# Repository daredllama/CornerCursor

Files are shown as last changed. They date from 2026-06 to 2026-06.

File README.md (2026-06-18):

**Reviewer, please look at the "LookOut Vids" folder here (https://drive.google.com/drive/folders/1z2TElufV9nIlRgEDV5de165D_nGBTV_t?usp=drive_link) to count the hours from those videos. The videos are named by their date (month.day). It should constitute about 16 hours, considering each second of a video is one MINUTE of actual time (The LookOut lapse program takes one photo every minute). For further inquiries, you can reach out to Evan Gan about the hours/videos.

# CornerCursor

A trackball mouse with 2 configurable buttons and a scroll ring. Made to be positioned on the corner of a laptop so that CADding is easier in any location.

Hardware created through Onshape. PCB made through KiCad. Firmware developed through VSCode.

## Features

- 3d printed case 
- Trackball navigation using PMW-3360 sensor
- Scroll Ring using 40 magnets with Hall Effect sensors
- 2 buttons
- Firmware designed for CAD use in Onshape

## Status

Currently unfinished. CAD, KiCAD, and Firmware are complete, but no actual model has been built. Debugging afterwards would also be expected.

## CAD Model

This is the overall build for the CornerCursor, which includes the case and the trackball.
Made using Onshape



## PCB

This is the schematic, PCB, and a render of the board. Note that the off-board component, such as the Hall effect sensor and USB-C connector, is not shown on the PCB> 

Schematic



PCB



Render

CornerCursor

## Firmware

Firmware sets up a 2-button trackball mouse that uses a PMW3360 sensor and a scroll ring.

To flash the software onto the board, connect your device to the mouse. A RPI-RP2 drive should show up, at which point you can drag the given UF2 file. To flash it again, hold the BOOT button and press the RESET button on the board.

## Assembly

1. Solder the necessary parts on the PCB, using the schematic and PCB image as reference. (Remember, PMW 3360 has its won lens)
2. Attach the board onto the bottom case using 2 M3X2 screws (They will go into plastic).
3. Wire the Hall effect sensor through the hole on the part named "top".
4. Attach the "top" part to the base case using 2 M3x8 screws.
5. Screw the two buttons to the bottom base using 4 M3x6 screws.
6. Attach the top case to the bottom case using 3 M3x12 screws.
7. Place the big bearing on the "top" part and attach neodymium magnets to the ring.
8. Place static bearings into divots in the "top" part and then place the trackball.

## Bill oF Materials

Full Bill of Materials located in the BOM file.

## Notes

AI Usage in this project was used for research, such as tutorials and datasheets; none of the code or CAD is AI-generated

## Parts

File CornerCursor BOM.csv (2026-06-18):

CornerCursor
BILL OF MATERIALS
Item | Quatitiy | Unit Price | Total Price | Notes
PMW3360 Sensor | 1.00 | 10.00 | 10.00
38mm trackball | 1.00 | 9.99 | 9.99 | https://ploopy.co/shop/tracking-ball/
W25Q128JVS Flash Storage | 1.00 | 2.00 | 2.00
ABM8-272-T3 Crystal | 1.00 | 0.60 | 0.60
TCR2F19 LDO regulator | 1.00 | 0.20 | 0.20
TLV73333PDBVR LDO regulator | 1.00 | 0.20 | 0.20
RP2040 chip | 1.00 | 1.00 | 1.00
D2LS-20M switch | 2.00 | 1.50 | 3.00
100n capacitor (Metric 0603) | 11.00 | 0.25 | 2.75
1u capactior (Metric 0603) | 5.00 | 0.25 | 1.25
0.1u capacitor (Metric 0603) | 1.00 | 0.25 | 0.25
15p capacitor (Metric 0603) | 2.00 | 0.25 | 0.50
4.7u capacitor (Metric 0603) | 1.00 | 0.25 | 0.25
39 resisitor (Metric 0603) | 1.00 | 0.20 | 0.20
10k resisitor (Metric 0603) | 2.00 | 0.20 | 0.40
27.4 resistor (Metric 0603) | 2.00 | 0.20 | 0.40
1k resistor (Metric 0603) | 2.00 | 0.20 | 0.40
SS49E Hall Effect sensor | 2.00 | 3.00 | 6.00
USB C to 4 Pin Connector | 5.00 | 1.00 | 5.00
B3S-1000 switch | 2.00 | 0.75 | 1.50
2mm Zirconia Oxide Static Bearing | 3.00 | 2.00 | 6.00
2x2mm neodymium cylinder magnets (axially magnetized) | 40.00 | 0.15 | 6.00
6808-ZZ Ball Bearing 40x52x7 Shielded | 1.00 | 22.00 | 22.00
Wires to hookup hall sensor |  |  | 0.00
M3x6 countersunk screws (Buttons) | 4.00 | 0.20 | 0.80
M3x8 countersunk screws (Top) | 2.00 | 0.20 | 0.40
M3x2 countersunk screws (Board) | 2.00 | 0.20 | 0.40
M3x12 countersunk screws (Case) | 3.00 | 0.20 | 0.60
 |  | Price for All: | 82.09

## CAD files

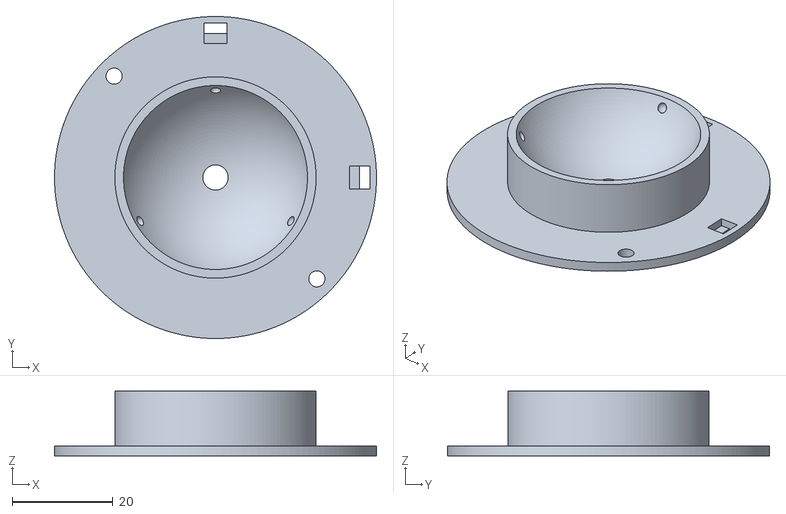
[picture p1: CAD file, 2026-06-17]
CAD/top.stl
64.0 x 64.0 x 12.9

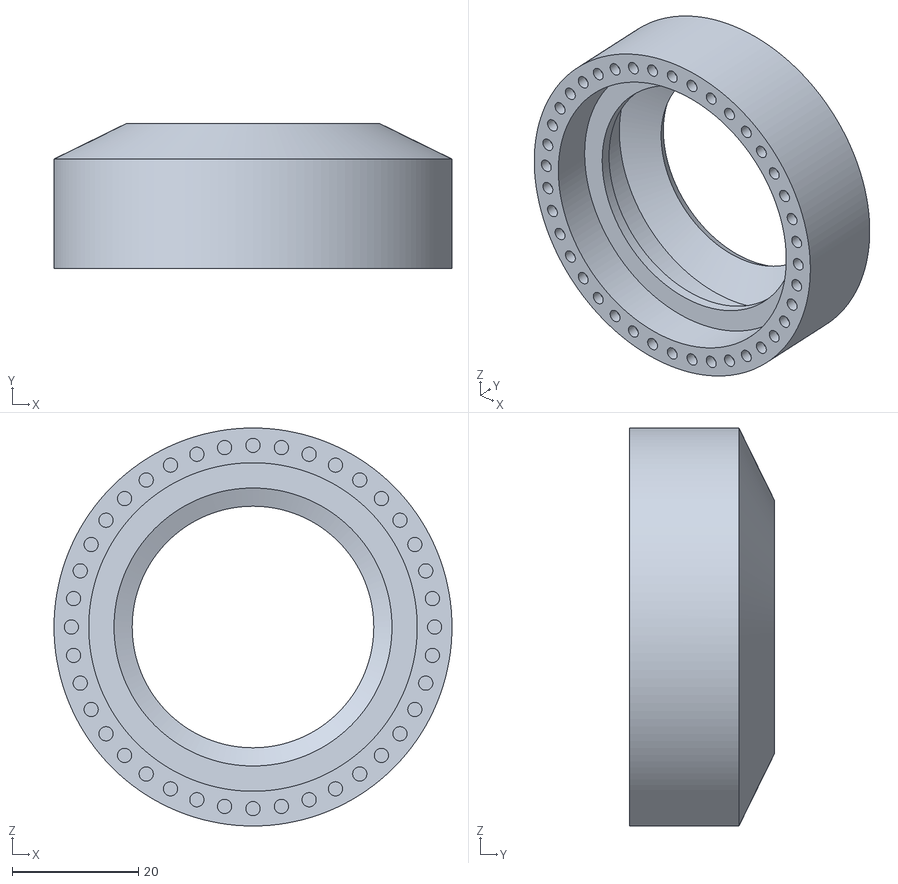
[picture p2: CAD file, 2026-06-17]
CAD/ring.stl
63.0 x 23.0 x 63.0

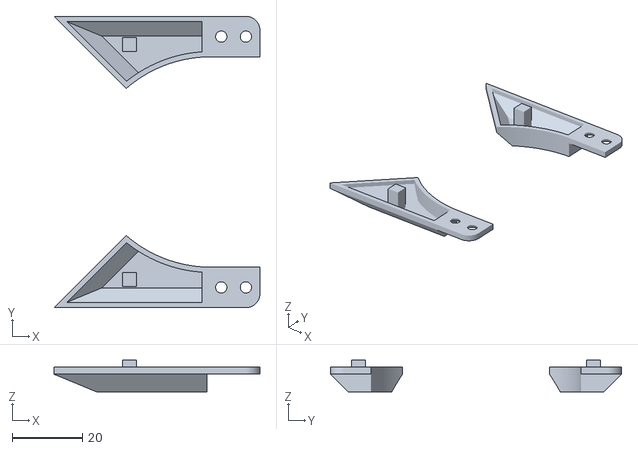
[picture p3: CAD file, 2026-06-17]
CAD/buttons.stl
58.5 x 82.7 x 9.00

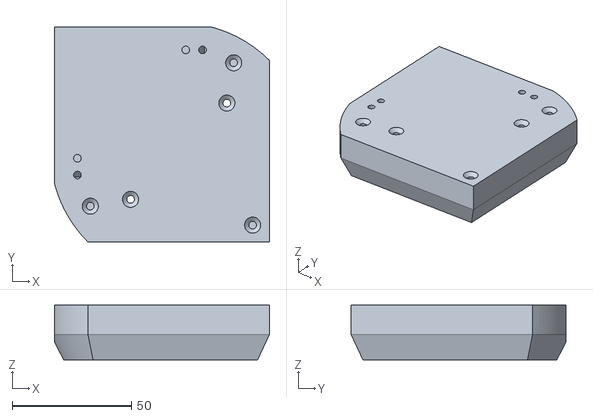
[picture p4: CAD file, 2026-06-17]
CAD/case.stl
90.0 x 90.0 x 23.0

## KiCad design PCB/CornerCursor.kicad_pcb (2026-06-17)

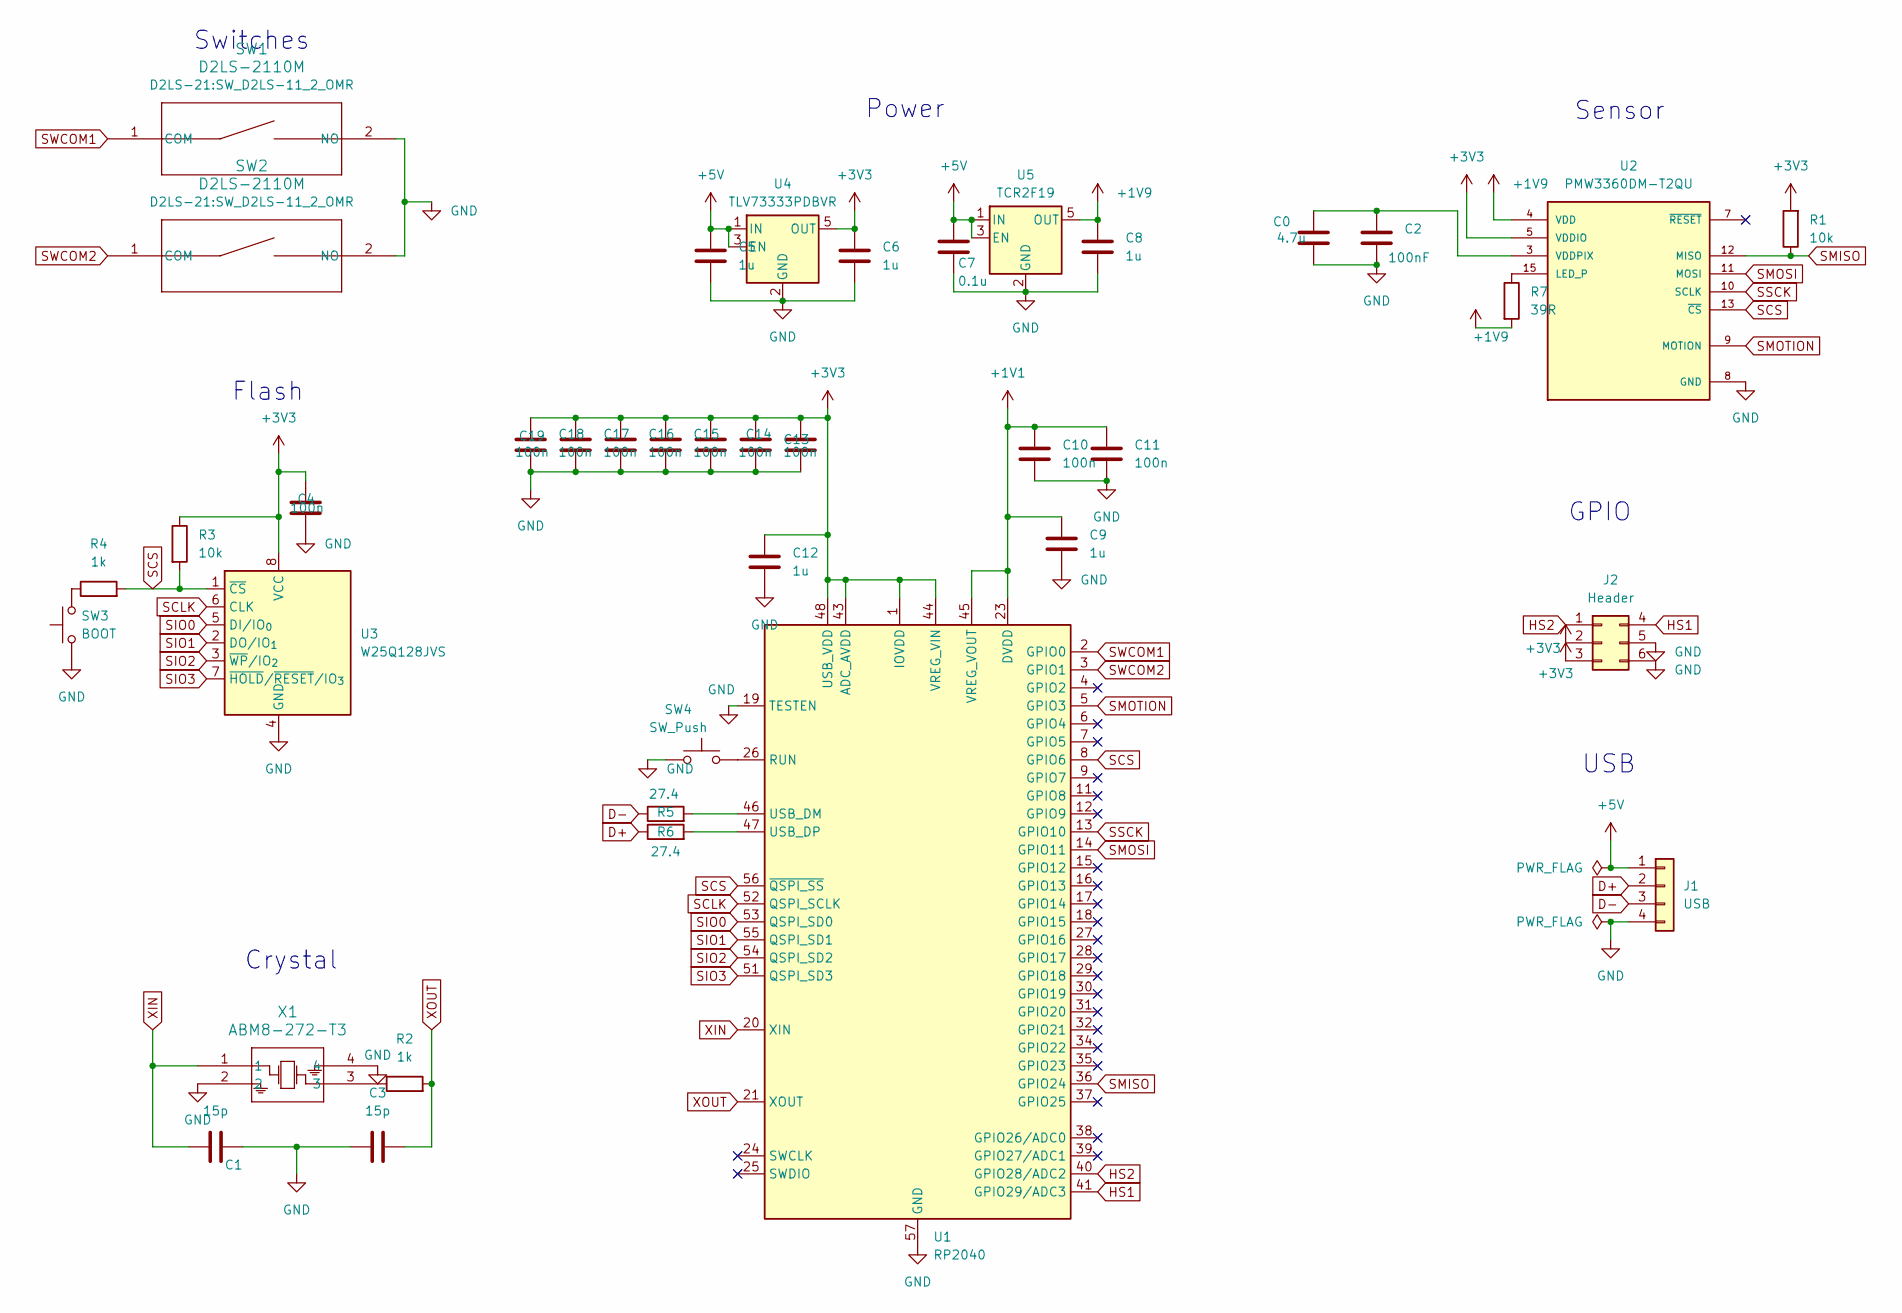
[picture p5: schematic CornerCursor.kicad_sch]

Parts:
C0: 4.7u; C_0603_1608Metric
C1, C3: 15p; C_0603_1608Metric
C2: 100nF; C_0603_1608Metric
C4, C10, C11, C13, C14, C15, C16, C17, C18, C19: 100n; C_0603_1608Metric
C5, C6, C8, C9, C12: 1u; C_0603_1608Metric
C7: 0.1u; C_0603_1608Metric
J1: USB; SolderWire-0.1sqmm_1x04_P3.6mm_D0.4mm_OD1mm
J2: Header; SolderWire-0.1sqmm_1x06_P3.6mm_D0.4mm_OD1mm
R1, R3: 10k; R_0603_1608Metric
R2, R4: 1k; R_0603_1608Metric
R5, R6: 27.4; R_0603_1608Metric
R7: 39R; R_0603_1608Metric
SW1, SW2: D2LS-2110M; SW_D2LS-11_2_OMR
SW3: BOOT; SW_SPST_B3S-1000
SW4: SW_Push; SW_SPST_B3S-1000
U1: RP2040; QFN-56-1EP_7x7mm_P0.4mm_EP3.2x3.2mm
U2: PMW3360DM-T2QU; PMW3360; MANUFACTURER_PART_NUMBER PMW3360DM-T2QU
U3: W25Q128JVS; SOIC-8_5.3x5.3mm_P1.27mm
U4: TLV73333PDBVR; DBV0005A_N
U5: TCR2F19; SOT-25_SMV_TOS
X1: ABM8-272-T3; ABM8-272-T3_ABR

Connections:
+1V1: C9.2, C10.1, C11.1, U1.23 (DVDD), U1.45 (VREG_VOUT), U1.50 (DVDD)
+1V9: C8.1, R7.2, U2.4 (VDD), U5.5 (OUT)
+3V3: C4.2, C6.1, C12.2, C13.1, C14.1, C15.1, C16.1, C17.1, C18.1, C19.1, J2.2, J2.3, R1.2, R3.1, U1.1 (IOVDD), U1.10 (IOVDD), U1.22 (IOVDD), U1.33 (IOVDD), U1.42 (IOVDD), U1.43 (ADC_AVDD), U1.44 (VREG_VIN), U1.48 (USB_VDD), U1.49 (IOVDD), U2.5 (VDDIO), U3.8 (VCC), U4.5 (OUT)
+5V: C5.1, C7.1, J1.1, U4.1 (IN), U4.3 (EN), U5.1 (IN), U5.3 (EN)
D+: J1.2, R6.1
D-: J1.3, R5.1
GND: C0.2, C1.2, C2.2, C3.1, C4.1, C5.2, C6.2, C7.2, C8.2, C9.1, C10.2, C11.2, C12.1, C13.2, C14.2, C15.2, C16.2, C17.2, C18.2, C19.2, J1.4, J2.5, J2.6, SW1.2 (NO), SW2.2 (NO), SW3.1, SW4.1, U1.19 (TESTEN), U1.57 (GND), U2.8 (GND), U3.4 (GND), U4.2 (GND), U5.2 (GND), X1.2, X1.4
HS1: J2.4, U1.41 (GPIO29/ADC3)
HS2: J2.1, U1.40 (GPIO28/ADC2)
unnamed: R2.1, X1.3
unnamed: R4.1, SW3.2
unnamed: SW4.2, U1.26 (RUN)
unnamed: R5.2, U1.46 (USB_DM)
unnamed: R6.2, U1.47 (USB_DP)
unnamed: R7.1, U2.15 (LED_P)
unnamed: C0.1, C2.1, U2.3 (VDDPIX)
SCLK: U1.52 (QSPI_SCLK), U3.6 (CLK)
SCS: R3.2, R4.2, U1.8 (GPIO6), U1.56 (~QSPI_SS), U2.13 (~CS), U3.1 (~CS)
SIO0: U1.53 (QSPI_SD0), U3.5 (DI/IO_{0})
SIO1: U1.55 (QSPI_SD1), U3.2 (DO/IO_{1})
SIO2: U1.54 (QSPI_SD2), U3.3 (~WP/IO_{2})
SIO3: U1.51 (QSPI_SD3), U3.7 (~HOLD/~RESET/IO_{3})
SMISO: R1.1, U1.36 (GPIO24), U2.12 (MISO)
SMOSI: U1.14 (GPIO11), U2.11 (MOSI)
SMOTION: U1.5 (GPIO3), U2.9 (MOTION)
SSCK: U1.13 (GPIO10), U2.10 (SCLK)
SWCOM1: SW1.1 (COM), U1.2 (GPIO0)
SWCOM2: SW2.1 (COM), U1.3 (GPIO1)
XIN: C1.1, U1.20 (XIN), X1.1
XOUT: C3.2, R2.2, U1.21 (XOUT)

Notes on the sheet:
Switches
Flash
Sensor
Power
USB
GPIO
Crystal

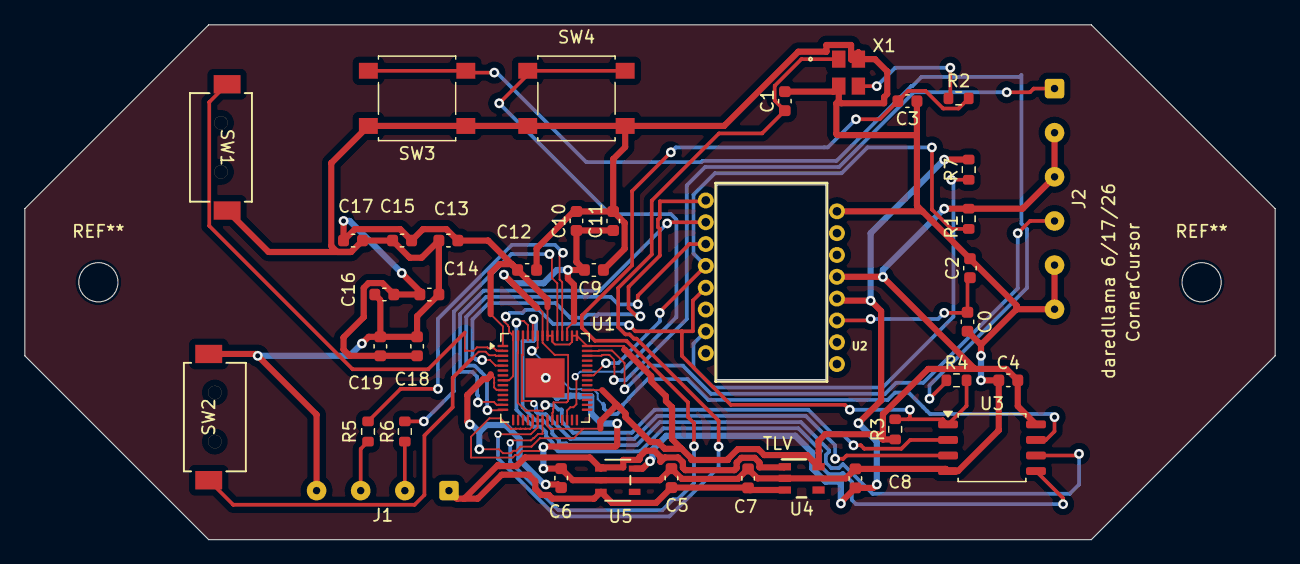
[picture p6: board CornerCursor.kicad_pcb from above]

Board: 2 copper layers, 102.0 x 42.0 mm, 39 parts (0 on the bottom side), 30 nets.

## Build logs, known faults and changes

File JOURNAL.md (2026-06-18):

# Journal

Corner Cursor

A portable trackball mouse

Started: 5/26/26

Current Hours: 33.3

## Day 1: May 26

Researched a lot about different configurations of trackball, and landed on a configuration that seemed suitable for the use it was meant for.
The main choice was between a thumb-controlled trackball and an index-controlled trackball. Ultimately ended up picking the index-controlled trackball because it was easier to use.
Also, it seemed that the position of the buttons would be more comfortable if the index finger were used instead of the thumb.



Started fleshing out the basic equipment that would be required ot build a basic trackball, which would be useful to figure out the size of everything while
cadding.



**Total Time: 2 hrs**

## Day 2: May 27

Mainly focused on the equipment that would be required to build the trackball, trying to get more specific with the equipment that would be used. This would help with the dimension that I would have to account for while trying to CAD. Turns out there are different forms of bearings for the trackball, but static bearings seemed the best. There are also different materials, but Zirconia Oxide seemed the most common. In terms of the sensor, Pixart has two primary ones that are in use. While the PMW-3360 is better, it is bigger compared to the PAW-3222.



**Total Time: 1 hr**

## Day 3: May 28

Finished with most of the logistics of how everything was going to work, including how to track the motion of the scroll ring and what switches I would use for the buttons. I found a previous custom trackball with a scroll ring that used magnets and Hall effect sensors to track them, which seemed to work for my situation. The switches would be miniseithces made for mice from Omron.



Began CADding out the main case for the mouse, and with most of the materials figured out, I was able to know most of the logistics of what I had to do. I decided to put the trackball in the top right of the mouse and the two buttons next to each other in the bottom right corner.



**Total Time: 2 hrs**

## Day 4: May 30

Worked out the logistics for CADing, primarily regarding the holder for the trackball. It turns out there are specific angles that can be used for the trackball. Originally, I was planning to use a 45-degree angle, but that seemed too steep, so I switched to a 60-degree angle, which was more relaxed.



Finished with the design of most of the case, including the position and dimension of the buttons, and the basic design of the scroll ring was also being finished.



Began with the holes to connect each part of the base, and making sure that there was still enough space for the PCB after the holes were completed. Also chamfered and filleted some of the corners of the CAD in order to make the case look more appealing.



Continued with making the holes in the case, to the point that I could fully assemble the full model in an assembly.



**Total Time: 4 hrs**

## Day 5: May 31

Worked on finishing up the pressing mechanism for the buttons so that I was actually able to mount them and use them to click the switches.



Began on the schematic for the PCB. I originally intended to use the Seeed RP2040 as the microcontroller board because that is what I had used previously for a previous project with a keyboard. 



While doing a little more research, I found that maybe the Seeed board did not have enough ports, and I would probably just have to use the RP2040 chip in my design, which is a lot more complicated because it needed many more things rather than just hooking up components to each other. I was going to save that for the next session, though.



**Total Time: 3 hrs**

## Day 6: June 2

I had my second thoughts about using the Hall Effect sensor, which was whether it was really the best way to track the movement of the scroll ring. My doubts stemmed from my lack of knowledge of how they worked and how to wire them in KiCAd. However, after doing more research about the other methods of how to (mechanical & optical), it seemed that the Hall Effect sensor was the way to go.

**Total Time: 0.3 hrs**

## Day 7: June 4

The day of reckoning came when I had to deal with how to use the RP2040 on its own. I thought I would be cooked because there were a lot of pins, but I ended up just using the hardware handbook thing that they recommended in order to get the basic stuff down. It seemed my worries were not valid.



I began feeling more comfortable as I got the symbols for the switches and the flash memory as well as the crystal that would serve as a timer. The hardware sheet that Raspberry provides is very useful because it provides basically all of the example schematics, which I can cross-reference with custom trackballs already on git.



Using the datasheet, I began wiring up the capacitors and the resistors for the separate components. I've finished the wiring for the sensor for the trackball.



**Total Time: 3 hrs**

## Day 8: June 5

I finished up a lot of the PCB schematic in KiCad that was left. More specifically, for the crystal, USB, flash, and switches, I did the capacitances as well as the resistance.



**Total Time: 1.5 hrs**

## Day 9: June 12

I switched over to Horizons from Fallout today.  In order to make this project shippable to get my hours, I had to properly document everything in GitHub. So, I spent most of my time writing the journal for the repo and setting up other things.



With most of the GitHub stuff done, I began to finish the schematic on KiCad. I pretty quickly did all of the connections for the remaining stuff, which was the decoupling capacitors on the RP2040 and the power supply. However, I did manage to finish the schematic, and unfortunately would have to fix all the problems in the ERC now.



**Total Time: 3.3 hrs**

## Day 10: June 15

I began by verifying all of the connections that I had made previously, as I had kind of been rushing. I fixed the errors, and I was off to assigning footprints to all the symbols. I imported many of the footprints, which was kind of confusing because the imported ones were not showing up. However, eventually, I got it to work. I also found out the different sizes for capacitors and resistors.



After finishing off the footprint assignments, it was time to fix the rest of the problems with the ERC. Most of the warnings were simple to fix because they had to do with having to fix wires or edit symbols so that they fit properly. However, there was one error and warning that was evading me, which had something to do with a GND pin and a +3v3 pin. As much as I tried to figure out what the problem was, I could not fix it, so I just moved on to the PCB editor, hoping that it would not cause any problems.



I imported all of the footprints into the PCB editor and laid out all the components properly. I used my CAD model in order to accurately replicate the usable dimensions for the board. Although it seemed that I would not have enough space, in the end, it turned out that there was space.



From this point onward, it seemed kind of weird. From my past experiences, I knew that while traces were a tedious process, it was pretty straightforward about what you needed to connect. However, in this instance, it seemed that ratsnests were leading me to wire the wrong components together. For instance, it wanted me to wire the pads of the capacitor together, which did not seem correct. I even looked at some video tutorials, but I still didn't seem to be able to wire the correct pads.



**Total Time: 7.5 hrs**

## Day 11: June 16

Started with fixing the big problem that was bugging me before, which was the reason why previously I couldn't begin tracing. It turns out that the line of decoupling capacitors connected to the RP2040 had been wired incorrectly, which resulted in all of the GND nets turning into +3v3 nets. With that out of the way, I could begin successfully wiring the PCB, and it was pretty easy in the beginning.



Now the more challenging wiring came, and it was really hard. I had to use a lot of vias on order for the traces not to cut off each other. In hindsight, I should have thought about positioning the components on the board so that it would be easier for me to wire. For the first time, I used different sizes of traces so that I could make power lines thicker than signal ones.



**Total Time: 4.5 hrs**

## Day 12: June 16

Fixed up the remaining problem with the DRC in KiCad. The majority of the issues just came from small bits of traces being left out, and silkscreen making things problematic.



Used the code from a similar project to get the firmware working. It was pretty simple, as I only had to adjust some PINs. I did not realize, though, that on RP2040s, there are specific pins for the SPI protocol that are divided into different SPI blocks. This made me have to rewire some stuff, but in the end, it was not too much work. I finished up the repo today as well.

**Total Time: 1.5 hrs**

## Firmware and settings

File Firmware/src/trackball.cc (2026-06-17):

/* 
 * The MIT License (MIT)
 *
 * Copyright (c) 2022 Jacek Fedorynski
 * Copyright (c) 2019 Ha Thach (tinyusb.org)
 *
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
 */

#include <stdio.h>
#include <stdlib.h>
#include <string.h>

#include <bsp/board.h>
#include <tusb.h>

#include <pico/bootrom.h>
#include <pico/stdlib.h>

#include <hardware/adc.h>
#include <hardware/flash.h>
#include <hardware/gpio.h>

#include "crc.h"
#include "pmw3360.h"


#define USB_VID 0xCAFE
#define USB_PID 0xBAFA

#define CONFIG_VERSION 1
#define CONFIG_SIZE 22

#define NBUTTONS 2
#define RESOLUTION_MULTIPLIER 120

#define PRESUMED_FLASH_SIZE 2097152
#define CONFIG_OFFSET_IN_FLASH (PRESUMED_FLASH_SIZE - FLASH_SECTOR_SIZE)
#define FLASH_CONFIG_IN_MEMORY (((uint8_t*) XIP_BASE) + CONFIG_OFFSET_IN_FLASH)

uint button_pins[NBUTTONS] = { 0, 1 };

#define SENSOR0_SPI spi1
#define SENSOR0_MISO 24
#define SENSOR0_MOSI 11
#define SENSOR0_SCK 10
#define SENSOR0_NCS 6

#define HALL_SENSOR1_PIN 28
#define HALL_SENSOR2_PIN 29
#define HALL_SENSOR1_INPUT 2
#define HALL_SENSOR2_INPUT 3

#define V_RESOLUTION_BITMASK (1 << 0)
#define H_RESOLUTION_BITMASK (1 << 2)

PMW3360 sensor = PMW3360(SENSOR0_SPI, SENSOR0_MISO, SENSOR0_MOSI, SENSOR0_SCK, SENSOR0_NCS);

tusb_desc_device_t const desc_device = {
    .bLength = sizeof(tusb_desc_device_t),
    .bDescriptorType = TUSB_DESC_DEVICE,
    .bcdUSB = 0x0200,
    .bDeviceClass = 0x00,
    .bDeviceSubClass = 0x00,
    .bDeviceProtocol = 0x00,
    .bMaxPacketSize0 = CFG_TUD_ENDPOINT0_SIZE,

    .idVendor = USB_VID,
    .idProduct = USB_PID,
    .bcdDevice = 0x0100,

    .iManufacturer = 0x01,
    .iProduct = 0x02,
    .iSerialNumber = 0x00,

    .bNumConfigurations = 0x01,
};

uint8_t const desc_hid_report[] = {
    0x05, 0x01,                   // Usage Page (Generic Desktop Ctrls)
    0x09, 0x02,                   // Usage (Mouse)
    0xA1, 0x01,                   // Collection (Application)
    0x05, 0x01,                   //   Usage Page (Generic Desktop Ctrls)
    0x09, 0x02,                   //   Usage (Mouse)
    0xA1, 0x02,                   //   Collection (Logical)
    0x85, 0x01,                   //     Report ID (1)
    0x09, 0x01,                   //     Usage (Pointer)
    0xA1, 0x00,                   //     Collection (Physical)
    0x05, 0x09,                   //       Usage Page (Button)
    0x19, 0x01,                   //       Usage Minimum (0x01)
    0x29, 0x08,                   //       Usage Maximum (0x08)
    0x95, 0x08,                   //       Report Count (8)
    0x75, 0x01,                   //       Report Size (1)
    0x25, 0x01,                   //       Logical Maximum (1)
    0x81, 0x02,                   //       Input (Data,Var,Abs,No Wrap,Linear,Preferred State,No Null Position)
    0x05, 0x01,                   //       Usage Page (Generic Desktop Ctrls)
    0x09, 0x30,                   //       Usage (X)
    0x09, 0x31,                   //       Usage (Y)
    0x95, 0x02,                   //       Report Count (2)
    0x75, 0x10,                   //       Report Size (16)
    0x16, 0x00, 0x80,             //       Logical Minimum (-32768)
    0x26, 0xFF, 0x7F,             //       Logical Maximum (32767)
    0x81, 0x06,                   //       Input (Data,Var,Rel,No Wrap,Linear,Preferred State,No Null Position)
    0xA1, 0x02,                   //       Collection (Logical)
    0x85, 0x02,                   //         Report ID (2)
    0x09, 0x48,                   //         Usage (Resolution Multiplier)
    0x95, 0x01,                   //         Report Count (1)
    0x75, 0x02,                   //         Report Size (2)
    0x15, 0x00,                   //         Logical Minimum (0)
    0x25, 0x01,                   //         Logical Maximum (1)
    0x35, 0x01,                   //         Physical Minimum (1)
    0x45, RESOLUTION_MULTIPLIER,  //         Physical Maximum (RESOLUTION_MULTIPLIER)
    0xB1, 0x02,                   //         Feature (Data,Var,Abs,No Wrap,Linear,Preferred State,No Null Position,Non-volatile)
    0x85, 0x01,                   //         Report ID (1)
    0x09, 0x38,                   //         Usage (Wheel)
    0x35, 0x00,                   //         Physical Minimum (0)
    0x45, 0x00,                   //         Physical Maximum (0)
    0x16, 0x00, 0x80,             //         Logical Minimum (-32768)
    0x26, 0xFF, 0x7F,             //         Logical Maximum (32767)
    0x75, 0x10,                   //         Report Size (16)
    0x81, 0x06,                   //         Input (Data,Var,Rel,No Wrap,Linear,Preferred State,No Null Position)
    0xC0,                         //       End Collection
    0xA1, 0x02,                   //       Collection (Logical)
    0x85, 0x02,                   //         Report ID (2)
    0x09, 0x48,                   //         Usage (Resolution Multiplier)
    0x75, 0x02,                   //         Report Size (2)
    0x15, 0x00,                   //         Logical Minimum (0)
    0x25, 0x01,                   //         Logical Maximum (1)
    0x35, 0x01,                   //         Physical Minimum (1)
    0x45, RESOLUTION_MULTIPLIER,  //         Physical Maximum (RESOLUTION_MULTIPLIER)
    0xB1, 0x02,                   //         Feature (Data,Var,Abs,No Wrap,Linear,Preferred State,No Null Position,Non-volatile)
    0x35, 0x00,                   //         Physical Minimum (0)
    0x45, 0x00,                   //         Physical Maximum (0)
    0x75, 0x04,                   //         Report Size (4)
    0xB1, 0x03,                   //         Feature (Const,Var,Abs,No Wrap,Linear,Preferred State,No Null Position,Non-volatile)
    0x85, 0x01,                   //         Report ID (1)
    0x05, 0x0C,                   //         Usage Page (Consumer)
    0x16, 0x00, 0x80,             //         Logical Minimum (-32768)
    0x26, 0xFF, 0x7F,             //         Logical Maximum (32767)
    0x75, 0x10,                   //         Report Size (16)
    0x0A, 0x38, 0x02,             //         Usage (AC Pan)
    0x81, 0x06,                   //         Input (Data,Var,Rel,No Wrap,Linear,Preferred State,No Null Position)
    0xC0,                         //       End Collection
    0xC0,                         //     End Collection
    0xC0,                         //   End Collection
    0x06, 0x00, 0xFF,             //   Usage Page (Vendor Defined 0xFF00)
    0x09, 0x20,                   //   Usage (0x20)
    0x85, 0x03,                   //   Report ID (3)
    0x75, 0x08,                   //   Report Size (8)
    0x95, CONFIG_SIZE,            //   Report Count (CONFIG_SIZE)
    0xB1, 0x02,                   //   Feature (Data,Var,Abs,No Wrap,Linear,Preferred State,No Null Position,Non-volatile)
    0xC0,                         // End Collection
};

#define CONFIG_TOTAL_LEN (TUD_CONFIG_DESC_LEN + TUD_HID_DESC_LEN)
#define EPNUM_HID 0x81

uint8_t const desc_configuration[] = {
    // Config number, interface count, string index, total length, attribute, power in mA
    TUD_CONFIG_DESCRIPTOR(1, 1, 0, CONFIG_TOTAL_LEN, 0, 100),

    // Interface number, string index, protocol, report descriptor len, EP In address, size & polling interval
    TUD_HID_DESCRIPTOR(0, 0, HID_ITF_PROTOCOL_NONE, sizeof(desc_hid_report), EPNUM_HID, CFG_TUD_HID_EP_BUFSIZE, 1)
};

char const* string_desc_arr[] = {
    (const char[]){ 0x09, 0x04 },  // 0: is supported language is English (0x0409)
    "RP2040+PMW3360",              // 1: Manufacturer
    "Trackball",                   // 2: Product
};

struct __attribute__((packed)) hid_report_t {
    uint8_t buttons;
    int16_t dx;
    int16_t dy;
    int16_t vwheel;
    int16_t hwheel;
};

hid_report_t report;

enum class ButtonFunction : int8_t {
    NO_FUNCTION = 0,
    BUTTON1 = 1,
    BUTTON2 = 2,
    BUTTON3 = 3,
    BUTTON4 = 4,
    BUTTON5 = 5,
    BUTTON6 = 6,
    BUTTON7 = 7,
    BUTTON8 = 8,
    CLICK_DRAG = 9,
    SHIFT = 10,
};

enum class BallFunction : int8_t {
    NO_FUNCTION = 0,
    CURSOR_X = 1,
    CURSOR_Y = 2,
    VERTICAL_SCROLL = 3,
    HORIZONTAL_SCROLL = 4,
    CURSOR_X_INVERTED = -1,
    CURSOR_Y_INVERTED = -2,
    VERTICAL_SCROLL_INVERTED = -3,
    HORIZONTAL_SCROLL_INVERTED = -4,
};

enum class RingFunction : int8_t {
    NO_FUNCTION = 0,
    VERTICAL_SCROLL = 1,
    HORIZONTAL_SCROLL = 2,
    VERTICAL_SCROLL_INVERTED = -1,
    HORIZONTAL_SCROLL_INVERTED = -2,
};

enum class ConfigCommand : int8_t {
    NO_COMMAND = 0,
    RESET_INTO_BOOTSEL = 1,
};

struct __attribute__((packed)) config_t {
    uint8_t version;
    ConfigCommand command;
    BallFunction ball_function[2];
    BallFunction ball_shifted_function[2];
    uint8_t ball_cpi;
    uint8_t ball_shifted_cpi;
    RingFunction ring_function;
    RingFunction ring_shifted_function;
    ButtonFunction button_function[NBUTTONS];
    ButtonFunction button_shifted_function[NBUTTONS];
    uint32_t crc32;
};

config_t config = {
    .version = CONFIG_VERSION,
    .command = ConfigCommand::NO_COMMAND,
    .ball_function = { BallFunction::CURSOR_X, BallFunction::CURSOR_Y_INVERTED },
    .ball_shifted_function = { BallFunction::CURSOR_X, BallFunction::CURSOR_Y_INVERTED },
    .ball_cpi = 600 / 100,
    .ball_shifted_cpi = 100 / 100,
    .ring_function = RingFunction::VERTICAL_SCROLL,
    .ring_shifted_function = RingFunction::HORIZONTAL_SCROLL,
    .button_function = {
        ButtonFunction::BUTTON1,
        ButtonFunction::BUTTON2,

    },
    .button_shifted_function = {
        ButtonFunction::BUTTON1,
        ButtonFunction::BUTTON2,
       
    },
    .crc32 = 0,
};

uint8_t resolution_multiplier = 0;

// 0 = sensor X, 1 = sensor Y, 2 = ring
int accumulated_scroll[3] = { 0 };
uint64_t last_scroll_timestamp[3] = { 0 };

uint32_t prev_pin_state = 0xffffffff;
bool click_drag = false;
uint8_t current_cpi = 0;

int16_t handle_scroll(int axis, int16_t movement, uint8_t multiplier_mask) {
    int16_t ret = 0;
    if (resolution_multiplier & multiplier_mask) {
        ret = movement;
    } else {
        if (movement != 0) {
            last_scroll_timestamp[axis] = time_us_64();
            accumulated_scroll[axis] += movement;
            int ticks = accumulated_scroll[axis] / RESOLUTION_MULTIPLIER;
            accumulated_scroll[axis] -= ticks * RESOLUTION_MULTIPLIER;
            ret = ticks;
        } else {
            if ((accumulated_scroll[axis] != 0) &&
                (time_us_64() - last_scroll_timestamp[axis] > 1000000)) {
                accumulated_scroll[axis] = 0;
            }
        }
    }
    return ret;
}

int encoder_rotation = 0;
int prev_state1 = 0;

void encoder_task(void) {
    adc_select_input(HALL_SENSOR1_INPUT);
    uint16_t val1 = adc_read();
    adc_select_input(HALL_SENSOR2_INPUT);
    uint16_t val2 = adc_read();

    int state1 = prev_state1;
    if (val1 > 2670) {
        state1 = 1;
    }
    if (val1 < 1602) {
        state1 = -1;
    }

    int state2 = 0;
    if (val2 > 2048) {
        state2 = 1;
    }
    if (val2 < 2048) {
        state2 = -1;
    }

    if (prev_state1 != state1) {
        if (state1 == state2) {
            encoder_rotation--;
        }
        if (state1 == -state2) {
            encoder_rotation++;
        }
    }

    prev_state1 = state1;
}

void hid_task() {
    if (!tud_hid_ready()) {
        return;
    }

    memset(&report, 0, sizeof(report));

    uint32_t pin_state = gpio_get_all();

    bool shifted = false;

    // first pass to determine if we're in shifted state
    for (int i = 0; i < NBUTTONS; i++) {
        if (config.button_function[i] == ButtonFunction::SHIFT &&
            !(pin_state & (1 << button_pins[i]))) {
            shifted = true;
        }
    }

    // set CPI if not already correct
    uint8_t wanted_cpi = shifted ? config.ball_shifted_cpi : config.ball_cpi;
    if (current_cpi != wanted_cpi && wanted_cpi >= 1 && wanted_cpi <= 120) {
        sensor.set_cpi(wanted_cpi * 100);
        current_cpi = wanted_cpi;
    }

    for (int i = 0; i < NBUTTONS; i++) {
        ButtonFunction button_function =
            shifted ? config.button_shifted_function[i] : config.button_function[i];
        if (config.button_function[i] == ButtonFunction::SHIFT) {
            button_function = ButtonFunction::NO_FUNCTION;
        }
        switch (button_function) {
            case ButtonFunction::NO_FUNCTION:
            case ButtonFunction::SHIFT:
                break;
            case ButtonFunction::BUTTON1:
            case ButtonFunction::BUTTON2:
            case ButtonFunction::BUTTON3:
            case ButtonFunction::BUTTON4:
            case ButtonFunction::BUTTON5:
            case ButtonFunction::BUTTON6:
            case ButtonFunction::BUTTON7:
            case ButtonFunction::BUTTON8: {
                int button = static_cast<int>(button_function) - 1;
                if (!(pin_state & (1 << button_pins[i]))) {
                    report.buttons |= 1 << button;
                }
                break;
            }
            case ButtonFunction::CLICK_DRAG:
                if ((prev_pin_state & (1 << button_pins[i])) &&
                    !(pin_state & (1 << button_pins[i]))) {
                    click_drag = !click_drag;
                }
                break;
        }
    }

    if (click_drag) {
        report.buttons |= 1 << 0;
    }

    prev_pin_state = pin_state;

    sensor.update();
    for (int axis = 0; axis < 2; axis++) {
        int16_t movement = sensor.movement[axis];
        BallFunction ball_function =
            shifted ? config.ball_shifted_function[axis] : config.ball_function[axis];
        if (static_cast<int>(ball_function) < 0) {
            movement *= -1;
        }
        switch (ball_function) {
            case BallFunction::NO_FUNCTION:
                break;
            case BallFunction::CURSOR_X:
            case BallFunction::CURSOR_X_INVERTED:
                report.dx += movement;
                break;
            case BallFunction::CURSOR_Y:
            case BallFunction::CURSOR_Y_INVERTED:
                report.dy += movement;
                break;
            case BallFunction::VERTICAL_SCROLL:
            case BallFunction::VERTICAL_SCROLL_INVERTED:
                report.vwheel += handle_scroll(axis, movement, V_RESOLUTION_BITMASK);
                break;
            case BallFunction::HORIZONTAL_SCROLL:
            case BallFunction::HORIZONTAL_SCROLL_INVERTED:
                report.hwheel += handle_scroll(axis, movement, H_RESOLUTION_BITMASK);
                break;
        }
    }

    int16_t ring_movement = encoder_rotation * RESOLUTION_MULTIPLIER;
    encoder_rotation = 0;
    RingFunction ring_function =
        shifted ? config.ring_shifted_function : config.ring_function;
    if (static_cast<int>(ring_function) < 0) {
        ring_movement *= -1;
    }
    switch (ring_function) {
        case RingFunction::NO_FUNCTION:
            break;
        case RingFunction::VERTICAL_SCROLL:
        case RingFunction::VERTICAL_SCROLL_INVERTED:
            report.vwheel += handle_scroll(2, ring_movement, V_RESOLUTION_BITMASK);
            break;
        case RingFunction::HORIZONTAL_SCROLL:
        case RingFunction::HORIZONTAL_SCROLL_INVERTED:
            report.hwheel += handle_scroll(2, ring_movement, H_RESOLUTION_BITMASK);
            break;
    }

    // uncomment to have pressing all four buttons reset into BOOTSEL
    // (convenient during development)
    // if (!(pin_state & (1 << button_pins[0]) ||
    //       pin_state & (1 << button_pins[1]) ||
    //       pin_state & (1 << button_pins[2]) ||
    //       pin_state & (1 << button_pins[3]))) {
    //     reset_usb_boot(0, 0);
    // }

    tud_hid_report(1, &report, sizeof(report));
}

void pin_init(uint pin) {
    gpio_init(pin);
    gpio_set_dir(pin, GPIO_IN);
    gpio_pull_up(pin);
}

void pins_init() {
    adc_init();
    adc_gpio_init(HALL_SENSOR1_PIN);
    adc_gpio_init(HALL_SENSOR2_PIN);
    for (int i = 0; i < NBUTTONS; i++) {
        pin_init(button_pins[i]);
    }
}

void sensor_init() {
    sensor.init();
}

void run_config_command() {
    // we probably shouldn't do this for config read from flash
    // or let's just not write any non-null command to flash
    if (config.command == ConfigCommand::RESET_INTO_BOOTSEL) {
        reset_usb_boot(0, 0);
    }
}

bool checksum_ok(const uint8_t* buffer) {
    return crc32(buffer, CONFIG_SIZE - 4) == ((config_t*) buffer)->crc32;
}

bool version_ok(const uint8_t* buffer) {
    return ((config_t*) buffer)->version == CONFIG_VERSION;
}

void load_config() {
    if (checksum_ok(FLASH_CONFIG_IN_MEMORY) && version_ok(FLASH_CONFIG_IN_MEMORY)) {
        memcpy(&config, FLASH_CONFIG_IN_MEMORY, CONFIG_SIZE);
    }
}

void persist_config() {
    uint8_t buffer[FLASH_PAGE_SIZE];
    memset(buffer, 0, sizeof(buffer));
    memcpy(buffer, &config, CONFIG_SIZE);
    uint32_t ints = save_and_disable_interrupts();
    flash_range_erase(CONFIG_OFFSET_IN_FLASH, FLASH_SECTOR_SIZE);
    flash_range_program(CONFIG_OFFSET_IN_FLASH, buffer, FLASH_PAGE_SIZE);
    restore_interrupts(ints);
}

int main() {
    stdio_init_all();
    board_init();
    load_config();
    pins_init();
    sensor_init();
    tusb_init();

    while (true) {
        tud_task();  // tinyusb device task
        encoder_task();
        hid_task();
    }

    return 0;
}

// Invoked when device is mounted
void tud_mount_cb() {
    // reset hi-res scroll for when we reboot from Windows into Linux
    resolution_multiplier = 0;
}

// Invoked when received GET DEVICE DESCRIPTOR
// Application return pointer to descriptor
uint8_t const* tud_descriptor_device_cb() {
    return (uint8_t const*) &desc_device;
}

// Invoked when received GET HID REPORT DESCRIPTOR
// Application return pointer to descriptor
// Descriptor contents must exist long enough for transfer to complete
uint8_t const* tud_hid_descriptor_report_cb(uint8_t itf) {
    return desc_hid_report;
}

// Invoked when received GET_REPORT control request
// Application must fill buffer report's content and return its length.
// Return zero will cause the stack to STALL request
uint16_t tud_hid_get_report_cb(uint8_t itf, uint8_t report_id, hid_report_type_t report_type, uint8_t* buffer, uint16_t reqlen) {
    if (report_id == 2 && reqlen >= 1) {
        memcpy(buffer, &resolution_multiplier, 1);
        return 1;
    }
    if (report_id == 3 && reqlen >= CONFIG_SIZE) {
        config.crc32 = crc32((uint8_t*) &config, CONFIG_SIZE - 4);
        memcpy(buffer, &config, CONFIG_SIZE);
        return CONFIG_SIZE;
    }

    return 0;
}

// Invoked when received SET_REPORT control request or
// received data on OUT endpoint ( Report ID = 0, Type = 0 )
void tud_hid_set_report_cb(uint8_t itf, uint8_t report_id, hid_report_type_t report_type, uint8_t const* buffer, uint16_t bufsize) {
    if (report_id == 2 && bufsize >= 1) {
        memcpy(&resolution_multiplier, buffer, 1);
    }
    if (report_id == 3 && bufsize >= CONFIG_SIZE) {
        if (checksum_ok(buffer) && version_ok(buffer)) {
            memcpy(&config, buffer, CONFIG_SIZE);
            run_config_command();
            persist_config();
        }
    }
}

// Invoked when received GET CONFIGURATION DESCRIPTOR
// Application return pointer to descriptor
// Descriptor contents must exist long enough for transfer to complete
uint8_t const* tud_descriptor_configuration_cb(uint8_t index) {
    return desc_configuration;
}

static uint16_t _desc_str[32];

// Invoked when received GET STRING DESCRIPTOR request
// Application return pointer to descriptor, whose contents must exist long enough for transfer to complete
uint16_t const* tud_descriptor_string_cb(uint8_t index, uint16_t langid) {
    uint8_t chr_count;

    if (index == 0) {
        memcpy(&_desc_str[1], string_desc_arr[0], 2);
        chr_count = 1;
    } else {
        // Note: the 0xEE index string is a Microsoft OS 1.0 Descriptors.
        // https://docs.microsoft.com/en-us/windows-hardware/drivers/usbcon/microsoft-defined-usb-descriptors

        if (!(index < sizeof(string_desc_arr) / sizeof(string_desc_arr[0])))
            return NULL;

        const char* str = string_desc_arr[index];

        // Cap at max char
        chr_count = strlen(str);
        if (chr_count > 31)
            chr_count = 31;

        // Convert ASCII string into UTF-16
        for (uint8_t i = 0; i < chr_count; i++) {
            _desc_str[1 + i] = str[i];
        }
    }

    // first byte is length (including header), second byte is string type
    _desc_str[0] = (TUSB_DESC_STRING << 8) | (2 * chr_count + 2);

    return _desc_str;
}

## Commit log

2026-06-12 Enhance README with project details and features
    Expanded the README with detailed features, status, CAD model, and additional sections.
2026-06-13 Revise JOURNAL.md with updates and new entries
    Updated current hours and added detailed entries for days 2 to 8, including research, design decisions, and progress on CAD and PCB schematics.
2026-06-17 Revise README with firmware details and images
    Updated firmware development tool and improved wording for clarity. Added schematic, PCB images, and firmware setup instructions.
2026-06-18 Update README with assembly steps and AI usage clarification
    Added assembly instructions and clarified AI usage in project.
